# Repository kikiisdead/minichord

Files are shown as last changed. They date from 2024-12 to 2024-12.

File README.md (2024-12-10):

# MINICHORD
 a mini omnichord made using Teensy 4.1 and the Teensy Audio Library for Digital Electronics at NYU Steinhardt Music Tech

# HARDWARE
 - Teensy 4.1 (could probably use a cheaper version but I have not tested it)
 - Teensy Audio Head
 - Adafruit CAP1188 
 - 7 MX compatible key switches (or equivalent, I used some Adafruit ones)
 - Adafruit SSD1306 (you may need to change the device ID)
 - Alps EC12E Vertical Rotary Encoder

[Mouser Project Page](https://www.mouser.com/ProjectManager/ProjectDetail.aspx?AccessID=75f0d25f79)

Does not include header pins, standoffs, or the cost to print the PCB.

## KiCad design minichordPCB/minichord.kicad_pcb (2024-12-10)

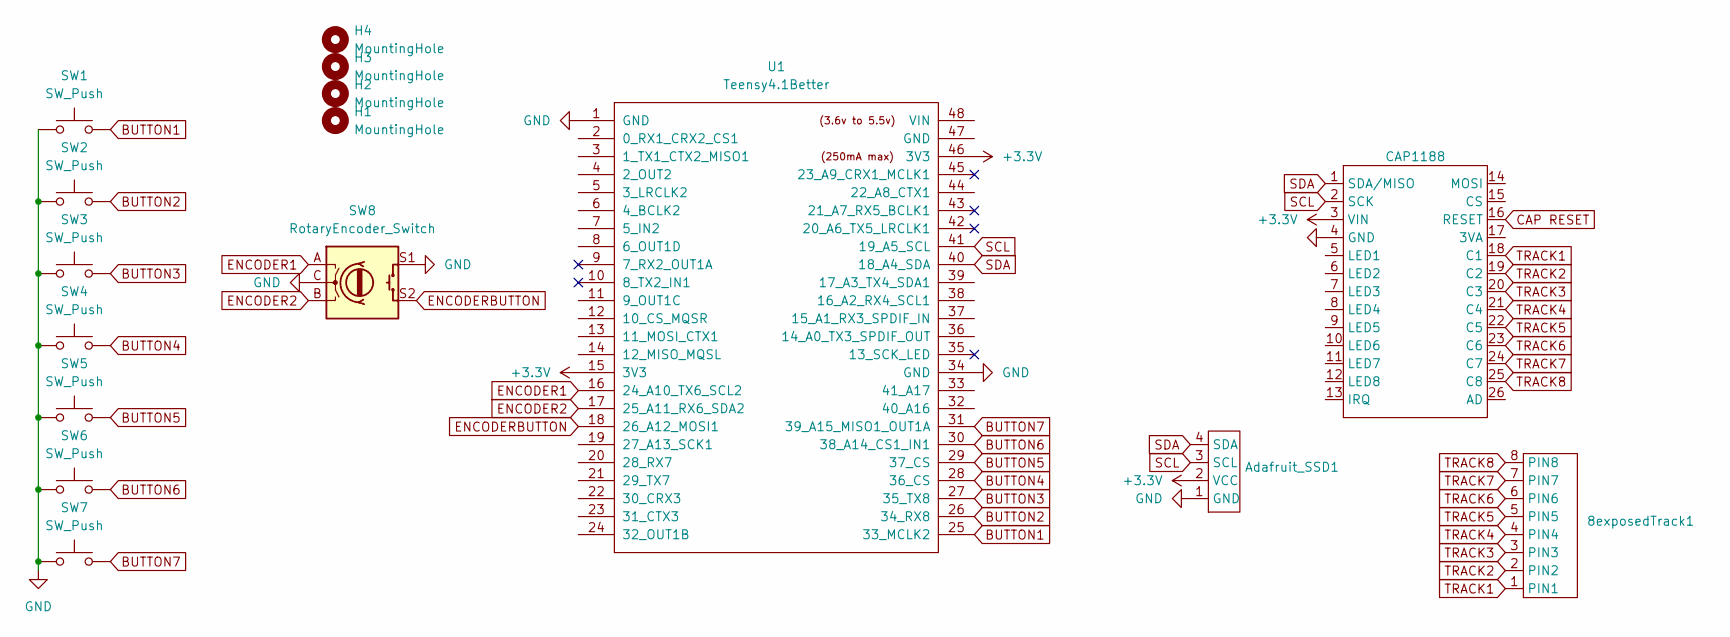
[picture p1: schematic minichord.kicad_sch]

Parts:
8exposedTrack1: 8touchCapacitiveTouch
Adafruit_SSD1: OLED_From_Amazon
H1, H2, H3, H4: MountingHole; MountingHole_2.7mm_M2.5
SW1, SW2, SW3, SW4, SW5, SW6, SW7: SW_Push; SW_Cherry_MX_1.00u_PCB
SW8: RotaryEncoder_Switch; RotaryEncoder_Alps_EC12E-Switch_Vertical_H20mm
U1: Teensy4.1Better; Teensy41Better
adafruit1: CAP1188; CAP1188 BREAKOUT

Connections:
+3.3V: Adafruit_SSD1.2 (VCC), U1.15 (3V3), U1.46 (3V3), adafruit1.3 (VIN)
BUTTON1: SW1.2, U1.25 (33_MCLK2)
BUTTON2: SW2.2, U1.26 (34_RX8)
BUTTON3: SW3.2, U1.27 (35_TX8)
BUTTON4: SW4.2, U1.28 (36_CS)
BUTTON5: SW5.2, U1.29 (37_CS)
BUTTON6: SW6.2, U1.30 (38_A14_CS1_IN1)
BUTTON7: SW7.2, U1.31 (39_A15_MISO1_OUT1A)
CAP RESET: adafruit1.16 (RESET)
ENCODER1: SW8.A, U1.16 (24_A10_TX6_SCL2)
ENCODER2: SW8.B, U1.17 (25_A11_RX6_SDA2)
ENCODERBUTTON: SW8.S2, U1.18 (26_A12_MOSI1)
GND: Adafruit_SSD1.1 (GND), SW1.1, SW2.1, SW3.1, SW4.1, SW5.1, SW6.1, SW7.1, SW8.C, SW8.S1, U1.1 (GND), U1.34 (GND), adafruit1.4 (GND)
SCL: Adafruit_SSD1.3 (SCL), U1.41 (19_A5_SCL), adafruit1.2 (SCK)
SDA: Adafruit_SSD1.4 (SDA), U1.40 (18_A4_SDA), adafruit1.1 (SDA/MISO)
TRACK1: 8exposedTrack1.1 (PIN1), adafruit1.18 (C1)
TRACK2: 8exposedTrack1.2 (PIN2), adafruit1.19 (C2)
TRACK3: 8exposedTrack1.3 (PIN3), adafruit1.20 (C3)
TRACK4: 8exposedTrack1.4 (PIN4), adafruit1.21 (C4)
TRACK5: 8exposedTrack1.5 (PIN5), adafruit1.22 (C5)
TRACK6: 8exposedTrack1.6 (PIN6), adafruit1.23 (C6)
TRACK7: 8exposedTrack1.7 (PIN7), adafruit1.24 (C7)
TRACK8: 8exposedTrack1.8 (PIN8), adafruit1.25 (C8)

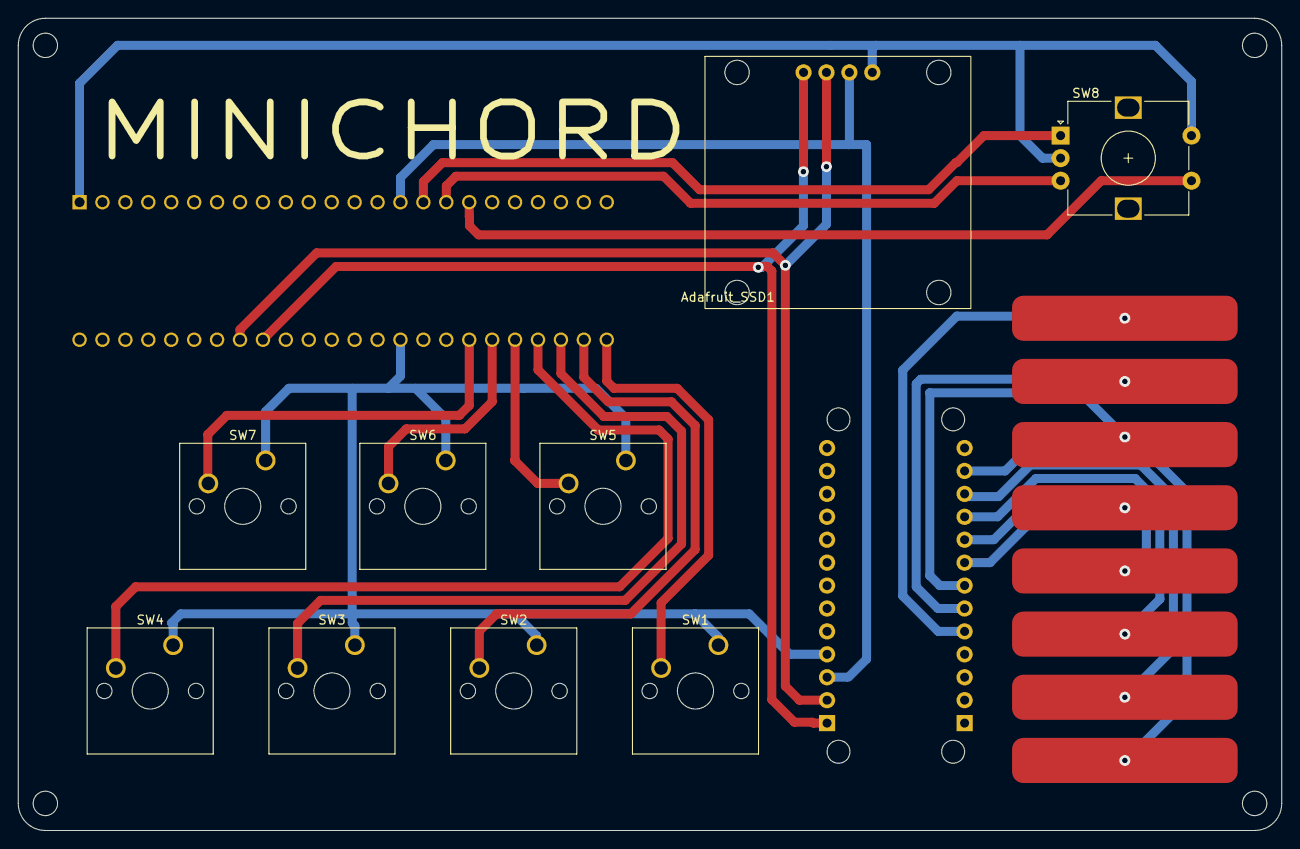
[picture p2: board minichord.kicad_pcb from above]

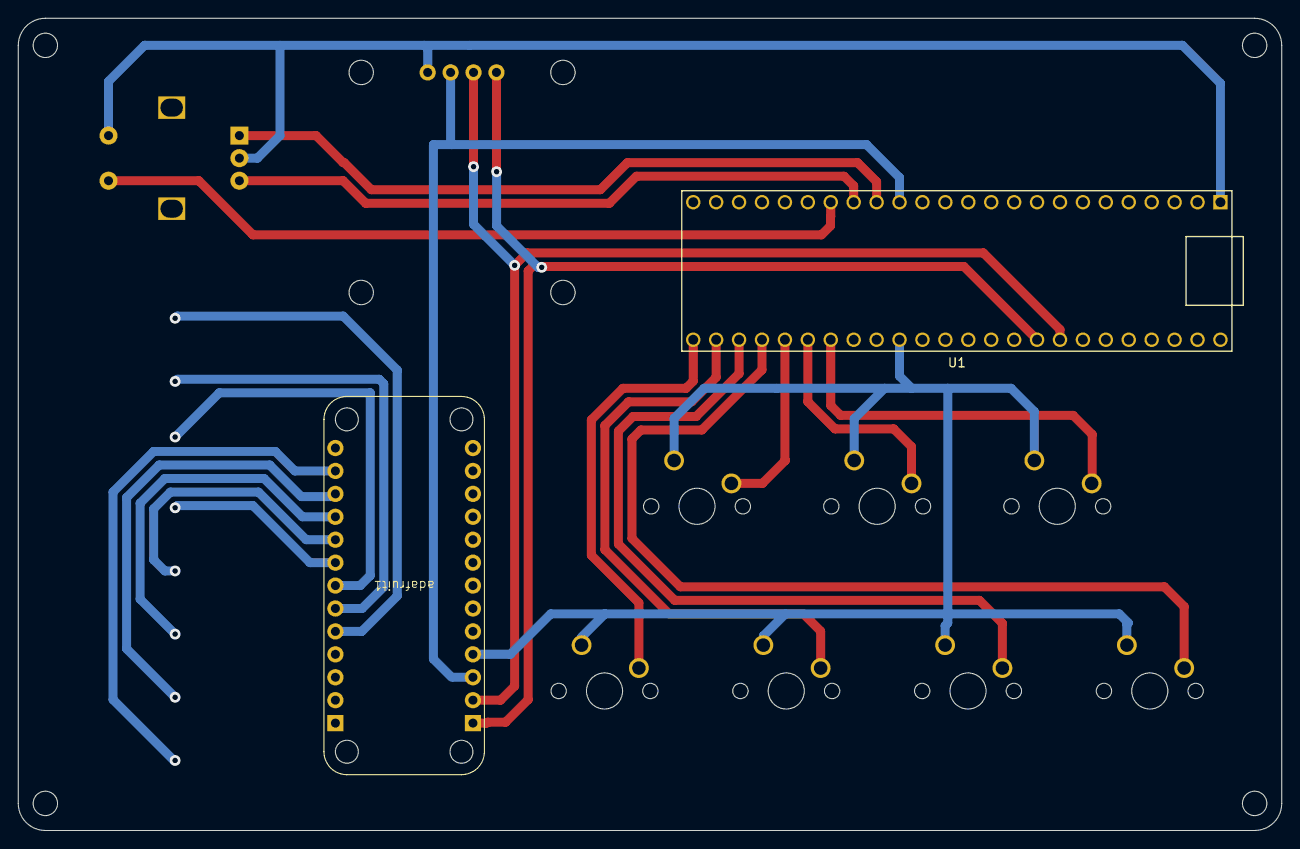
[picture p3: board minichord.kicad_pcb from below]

Board: 2 copper layers, 140.0 x 90.0 mm, 16 parts (2 on the bottom side), 22 nets.

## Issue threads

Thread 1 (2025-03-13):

Build process via PlatformIO fails. Libraries used for original project are not specified.

sinitsinmike, 2025-03-13:
There's an issue during a build process via PlatformIO.

Exect libraries used for original projetc not specified.

Processing teensy41 (platform: teensy; board: teensy41; framework: arduino)
----------------------------------------------------------------------------------------------------------------------------
Verbose mode can be enabled via `-v, --verbose` option
CONFIGURATION: https://docs.platformio.org/page/boards/teensy/teensy41.html
PLATFORM: Teensy (5.0.0) > Teensy 4.1
HARDWARE: IMXRT1062 600MHz, 512KB RAM, 7.75MB Flash
DEBUG: Current (jlink) External (jlink)
PACKAGES:
 - framework-arduinoteensy @ 1.159.0 (1.59)
 - tool-teensy @ 1.159.0 (1.59)
 - toolchain-gccarmnoneeabi-teensy @ 1.110301.0 (11.3.1)
Converting minichord.ino
LDF: Library Dependency Finder -> https://bit.ly/configure-pio-ldf
LDF Modes: Finder ~ chain, Compatibility ~ soft
Found 112 compatible libraries
Scanning dependencies...
Dependency Graph
|-- Adafruit SSD1306 @ 2.5.13
|-- Adafruit CAP1188 Library @ 1.1.3
|-- SD @ 1.3.0
|-- Audio @ 1.3
|-- EEPROM @ 2.0
|-- SerialFlash
|-- SPI @ 1.0
|-- Wire @ 1.0
|-- Adafruit GFX Library @ 1.12.0
|-- Encoder @ 1.4.4
Building in release mode

Compiling .pio\build\teensy41\libcb2\Audio\analyze_tonedetect.cpp.o

After the line above all text in yellow. indicating some issue:

.pio\libdeps\teensy41\SD\src\File.cpp: In constructor 'SDLib::File::File(SdFile, const char*)':
.pio\libdeps\teensy41\SD\src\File.cpp:25:11: warning: 'void* memcpy(void*, const void*, size_t)' writing to an object of type 'class SdFile' with no trivial copy-assignment; use copy-assignment or copy-initialization instead [-Wclass-memaccess]
   25 |     memcpy(_file, &f, sizeof(SdFile));
      |     ~~~~~~^~~~~~~~~~~~~~~~~~~~~~~~~~~
In file included from .pio\libdeps\teensy41\SD\src/SD.h:20,
                 from .pio\libdeps\teensy41\SD\src\File.cpp:15:
.pio\libdeps\teensy41\SD\src/utility/SdFat.h:151:7: note: 'class SdFile' declared here
  151 | class SdFile : public Print {
      |       ^~~~~~
Archiving .pio\build\teensy41\lib98b\libAdafruit SSD1306.a
.pio\libdeps\teensy41\SD\src\utility\SdFile.cpp: In member function 'uint8_t SdFile::open(SdFile*, const char*, uint8_t)':
Archiving .pio\build\teensy41\libecb\libAdafruit CAP1188 Library.a
.pio\libdeps\teensy41\SD\src\utility\SdFile.cpp:532:15: warning: taking address of packed member of 'directoryEntry' may result in an unaligned pointer value [-Waddress-of-packed-member]
  532 |     dateTime_(&p->creationDate, &p->creationTime);
      |               ^~~~~~~~~~~~~~~~
.pio\libdeps\teensy41\SD\src\utility\SdFile.cpp:532:15: warning: taking address of packed member of 'directoryEntry' may result in an unaligned pointer value [-Waddress-of-packed-member]
.pio\libdeps\teensy41\SD\src\utility\SdFile.cpp:532:33: warning: taking address of packed member of 'directoryEntry' may result in an unaligned pointer value [-Waddress-of-packed-member]
  532 |     dateTime_(&p->creationDate, &p->creationTime);
      |                                 ^~~~~~~~~~~~~~~~
.pio\libdeps\teensy41\SD\src\utility\SdFile.cpp:532:33: warning: taking address of packed member of 'directoryEntry' may result in an unaligned pointer value [-Waddress-of-packed-member]
.pio\libdeps\teensy41\SD\src\utility\SdFile.cpp: In member function 'uint8_t SdFile::sync(uint8_t)':
.pio\libdeps\teensy41\SD\src\utility\SdFile.cpp:1155:17: warning: taking address of packed member of 'directoryEntry' may result in an unaligned pointer value [-Waddress-of-packed-member]
 1155 |       dateTime_(&d->lastWriteDate, &d->lastWriteTime);
      |                 ^~~~~~~~~~~~~~~~~
.pio\libdeps\teensy41\SD\src\utility\SdFile.cpp:1155:17: warning: taking address of packed member of 'directoryEntry' may result in an unaligned pointer value [-Waddress-of-packed-member]
.pio\libdeps\teensy41\SD\src\utility\SdFile.cpp:1155:36: warning: taking address of packed member of 'directoryEntry' may result in an unaligned pointer value [-Waddress-of-packed-member]
 1155 |       dateTime_(&d->lastWriteDate, &d->lastWriteTime);
      |                                    ^~~~~~~~~~~~~~~~~
.pio\libdeps\teensy41\SD\src\utility\SdFile.cpp:1155:36: warning: taking address of packed member of 'directoryEntry' may result in an unaligned pointer value [-Waddress-of-packed-member]

tried the following SD lib: arduino-libraries/SD@^1.3.0
braydenanderson2014/BasicIOStream@^1.0.1

kikiisdead, 2025-03-13:
The way I have the PlatformIO project set up is that it's accessing the externals from the Arduino library. This is because I ported the project into VSCode from Arduino. You will have to install Arduino, install the dependencies, and it should work?

sinitsinmike, 2025-03-13:
Which particular SD library was used in this project? Also which version?

Closed 2025-03-13.

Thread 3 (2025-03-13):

Audio shield optional or required?

sinitsinmike, 2025-03-13:
If this device is assambled without the audio shield, then flashed.
Would it be able to work via USB MIDI?
Or the device would fail to boot and get in to infinite loop, waiting for the audio shield?
Would another dac work instead of the shield?
Perhaps pcm5102?

Closed 2025-03-13.

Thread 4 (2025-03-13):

Hex file

sinitsinmike, 2025-03-13:
Success, Tried to build it on Mac, instead of Windows and build process completed with no issues.
The display is lit up but blank. Just the snow, like on the old crt tv :)

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

kikiisdead, 2025-03-13:
There's an error on the PCB, make sure that the SDA and SCL buses are in the right place.

kikiisdead, 2025-03-21:
Sorry scratch that, the GND and VCC pins are swapped. I would just get some wire and attach it.

sinitsinmike, 2025-03-21:
If I plug the display up side down then pinout matches. I'll leave it like this for now, this is good enough for testing perposes ;)

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

Closed 2025-03-21.

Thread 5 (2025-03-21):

After successful build and upload, device restarts every 5-10 seconds. Blank screen. No sound.

sinitsinmike, 2025-03-21:
After compiling and uploading the code to teensy, I get the message in the terminal: CAP1188 found!, SSD1306 allocation success! And that's it, no further messages. Display is blank, and device restarts every 5-10 seconds. Your inpit would be greatly appreciated! Thank you!

sinitsinmike, 2025-03-21:
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

kikiisdead, 2025-03-21:
I just want to make sure that the audio head is installed correctly. Do you mind sending a picture of the bottom side of the board?

sinitsinmike, 2025-03-21:
I am using an alternative board. It is PCM5102. It is connected correctly. I've executed a simple code with a sine wave to make sure there's oudio out. I've ordered the audio shield you've used. It is in the mail. Will get it in a few weeks.

Yahoo Почта: Поиск, организация, успех

  пт, 21 мар. 2025 в 19:20 ***@***.***> написал(-а):
I just want to make sure that the audio head is installed correctly. Do you mind sending a picture of the bottom side of the board?

—
Reply to this email directly, view it on GitHub, or unsubscribe.
You are receiving this because you authored the thread.Message ID: ***@***.***>
kikiisdead left a comment (kikiisdead/minichord#5)
I just want to make sure that the audio head is installed correctly. Do you mind sending a picture of the bottom side of the board?

—
Reply to this email directly, view it on GitHub, or unsubscribe.
You are receiving this because you authored the thread.Message ID: ***@***.***>

sinitsinmike, 2025-03-21:
Also tried various displays with 0x3D and 0x3C addresses, adjusting the address in the code. Previously that didn't work, with your last changes both displays display text. But, rotating the encoder doesn't change any parameters. the text remais unchanged.

kikiisdead, 2025-03-21:
From what I can tell, the issue lies either in the EEPROM read or in the audio connection side of the code. I want to make sure that it is not a hardware issue that's why I'm asking for photos.

sinitsinmike, 2025-03-21:
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
Here are a few photos of the wiring.

sinitsinmike, 2025-03-21:
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

Closed 2025-03-21.

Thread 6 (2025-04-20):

Audio shield board

sinitsinmike, 2025-04-20:
Does your audio shield has an optional W25Q128JV or W25Q128FV chip soldered underneath? Or perhaps a 23LC1024 chip?

My Teensy doesn't have this chip, and that might be the reason why my Minichord doesn't fully boot up.

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

The mem chip on the photo. The docs and wiki says it is optional.
Does your shield has this solderred on?

Thank you!

kikiisdead, 2025-04-21:
I don't have a mem chip on mine. The oscillators don't use any memory and I'm not playing any samples. The only place that uses memory is saving chords between startup and shutdown which happens on the EEPROM. Can you describe what's happening?

sinitsinmike, 2025-04-21:
Previously I've raised the issue that minichord would not boot. Previously I've used different DAC.
You've replued that I have to use Teensy ausio shield.
I got that specific shield, but still no luck booting. I get the text on the screen, but no reaction to encoder nor to 3ncoder button presses.
The touch works, no sound, but the leds light up on touch board, so soldering is fine.
I have also tried alternative simple code to check the teensy audio board, and it produces sound, but not with minichord code.
Not sure what to try next.

Would realky appreciate any suggestions.
Yhank you!
Michael

kikiisdead, 2025-04-21:
Are you getting the message "I'm working" to the Serial Monitor?

sinitsinmike, 2025-04-21:
Ah, no. Not getting "I'm working" to the Serial Monitor.
Auto-restart is still happening every 10 seconds.
Rotating the encoder and or pressing buttons nor strumming doesn't make any difference. No sound. Rotating the encoder doesn't change anything on the screen.

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

Earlier, in another issue/git ticket you wrote:
"From what I can tell, the issue lies either in the EEPROM read or in the audio connection side of the code. From your photos, it looks like the program is stalling in the setup phase after the display and after the capacitive touch sensor. It never reaches the end of the setup phase because "I'm working" is not being printed to the terminal. This means that either the EEPROM.read is failing or the audio shield is not starting correctly.

The reason why the text on screen isn't changing is because we never reach the loop part of the program where that logic is handled. Everything is stalling in the set-up portion."
So something is off.
I've soldered everything correctly.
Ran some test code to check teensy audio shield, and it produces sound. So it is soldered correctly.

sinitsinmike, 2025-04-21:
May be audio libraries got updated. May be I should try to build using older arduino libraries.

kikiisdead, 2025-04-22:
I don't think it's a dependency issue as it seems to be building okay on my end, but try it and let me know if it works.

The program was seems to be written to the Teensy OK as it entered Serial mode and started printing things to the serial monitor. My hunch is that it might not have enough power or there is some sort of other runtime error. Do you know if the USB port you're using is powered?

kikiisdead, 2025-04-22:
I pushed an update that has a more verbose setup function so that there is more specificity where it is crashing.

sinitsinmike, 2025-04-22:
Unfortunately the serial output hasn't changed.

Reconnecting to /dev/cu.usbmodem162834701        Connected!
CAP1188 found!
SSD1306 allocation success!
Disconnected (read failed: [Errno 6] Device not configured)

sinitsinmike, 2025-04-22:
My Teensy audio shield is Rev D2.

sinitsinmike, 2025-04-22:
In January 2023, Rev D2 was created due to shortages on the 32 pin version of SGTL5000 and the [original SD socket](https://forum.pjrc.com/threads/71669). Rev D2 is functionally the same as Rev D, except the the I2C address selection pads. The I2C address is not configurable on the 20 pin SGTL5000 chip.

Could this be an issue?

sinitsinmike, 2025-04-22:
If I comment out:

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
The code goes a bit further.
So looks like initRoot(EEPROM.read(i)) is causing this.

kikiisdead, 2025-04-22:
`
#include <EEPROM.h>

int write = 10;

int read = 0;

void setup() {
  // put your setup code here, to run once:
  Serial.begin(9600);
  EEPROM.write(0, write);
  Serial.println(F("writing to EEPROM"));
  read = EEPROM.read(0);
  Serial.println(F("Reading from EEPROM"));
  Serial.println(read);
  while (true) {
  }
}

void loop() {
  // put your main code here, to run repeatedly:

}
`

could you test this code to see if the EEPROM is messing things up?

sinitsinmike, 2025-04-22:
16:56:13.381 -> writing to EEPROM
16:56:13.381 -> Reading from EEPROM
16:56:13.381 -> 10

sinitsinmike, 2025-04-22:
If I run:

/* EEPROM Read
 *
 * Reads the value of each byte of the EEPROM and prints it
 * to the computer.
 */

#include <EEPROM.h>

// start reading from the first byte (address 0) of the EEPROM
int address = 0;
byte value;

void setup()
{
  Serial.begin(9600);
}

void loop()
{
  // read a byte from the current address of the EEPROM
  value = EEPROM.read(address);

  Serial.print(address);
  Serial.print("\t");
  Serial.print(value, DEC);
  Serial.println();

  // advance to the next address of the EEPROM
  address = address + 1;

  // there are only 512 bytes of EEPROM, from 0 to 511, so if we're
  // on address 512, wrap around to address 0
  if (address == 512)
    address = 0;
  // Teensy 1.0 has 512 bytes
  // Teensy 2.0 has 1024 bytes
  // Teensy++ 1.0 has 2048 bytes
  // Teensy++ 2.0 has 4096 bytes

  delay(500);
}

I get:

16:56:13.381 -> writing to EEPROM
16:56:13.381 -> Reading from EEPROM
16:56:13.381 -> 10
16:57:15.049 -> 0	10
16:57:15.494 -> 1	0
16:57:16.021 -> 2	255
16:57:16.516 -> 3	0
16:57:17.010 -> 4	0
16:57:17.506 -> 5	0
16:57:18.000 -> 6	255
16:57:18.495 -> 7	255
16:57:19.020 -> 8	255
16:57:19.515 -> 9	255
16:57:20.008 -> 10	255
16:57:20.502 -> 11	0
16:57:20.995 -> 12	255
16:57:21.523 -> 13	0
16:57:22.017 -> 14	0
16:57:22.512 -> 15	0
16:57:23.008 -> 16	255
16:57:23.503 -> 17	255
16:57:23.998 -> 18	255
16:57:24.526 -> 19	255
16:57:25.017 -> 20	255

sinitsinmike, 2025-04-22:
Correction.
If I try modifying your code in minichord.ino like this:

    chords[i]->initRoot(EEPROM.read(i));
    Serial.println(F("EEPROM!"));
    chords[i]->setChordType((chordTypes)(EEPROM.read(i + 10)));
    Serial.println(F("Set Chord type!"));

I get the first serial print: EEPROM!
But I don't get the second one: Set Chord type!

So Set Chord type! never gets printed.

kikiisdead, 2025-04-22:
it might be something to do with the type casting from an enum. I'll see what I can do once my parts get in tomorrow.

sinitsinmike, 2025-04-23:
Swapped places 24 and 25, encoder works fine now.
Thanks again!

kikiisdead, 2025-04-23:
Of course I'm glad we figured it out!

Closed 2025-04-23.

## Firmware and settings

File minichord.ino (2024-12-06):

#include "chord.h"
#include "betterEncoder.h"
#include "voice.h"
#include "mixers.h"
#include "velocity.h"
#include "volume.h"
#include "chordType.h"
#include "chordRoot.h"
#include "animation.h"
#include <Audio.h>
#include <Wire.h>
#include <SPI.h>
#include <SD.h>
#include <SerialFlash.h>
#include <Adafruit_GFX.h>
#include <Adafruit_SSD1306.h>
#include <Adafruit_CAP1188.h>
#include <string.h>
#include <EEPROM.h>

// MEMORY ALLOCATION
// Addresses 0-6 are for the root note
// Addresses 10-16 are for the chord type
// don't want to write too many times so only write when changing off of the corresponding editMode

#define CHORDPIN1 33
#define CHORDPIN2 34
#define CHORDPIN3 35
#define CHORDPIN4 36
#define CHORDPIN5 37
#define CHORDPIN6 38
#define CHORDPIN7 39
#define EDITPIN 26

#define ROOTEDIT 0
#define CHORDEDIT 1
#define VOLEDIT 2
#define VELEDIT 3
#define ANIM 4

#define CAP1188_RESET -1

#define SCREEN_WIDTH 128     // OLED display width, in pixels
#define SCREEN_HEIGHT 64     // OLED display height, in pixels
#define OLED_RESET -1        // Reset pin # (or -1 if sharing Arduino reset pin)
#define SCREEN_ADDRESS 0x3C  ///< See datasheet for Address; 0x3D for 128x64, 0x3C for 128x32

Adafruit_SSD1306 display(SCREEN_WIDTH, SCREEN_HEIGHT, &Wire, OLED_RESET);

Adafruit_CAP1188 cap = Adafruit_CAP1188();

Voice sustainVoice1(WAVEFORM_TRIANGLE, 0.5);
Voice sustainVoice2(WAVEFORM_TRIANGLE, 0.5);
Voice sustainVoice3(WAVEFORM_TRIANGLE, 0.5);
Voice strumVoice1(WAVEFORM_TRIANGLE, 0.5);
Voice strumVoice2(WAVEFORM_TRIANGLE, 0.5);
Voice strumVoice3(WAVEFORM_TRIANGLE, 0.5);
Voice strumVoice4(WAVEFORM_TRIANGLE, 0.5);
Voice strumVoice5(WAVEFORM_TRIANGLE, 0.5);
Voice strumVoice6(WAVEFORM_TRIANGLE, 0.5);
Voice strumVoice7(WAVEFORM_TRIANGLE, 0.5);
Voice strumVoice8(WAVEFORM_TRIANGLE, 0.5);

Voice* voices[11] = { &sustainVoice1, &sustainVoice2, &sustainVoice3, &strumVoice1, &strumVoice2, &strumVoice3, &strumVoice4, &strumVoice5, &strumVoice6, &strumVoice7, &strumVoice8 };

AudioMixer11 mixer;
AudioOutputI2S i2sOut;
AudioControlSGTL5000 audioShield;
AudioConnection* patchCords[11];
AudioConnection patchCord1(mixer, 0, i2sOut, 0);
AudioConnection patchCord2(mixer, 0, i2sOut, 1);

Chord chord1(CHORDPIN1);
Chord chord2(CHORDPIN2);
Chord chord3(CHORDPIN3);
Chord chord4(CHORDPIN4);
Chord chord5(CHORDPIN5);
Chord chord6(CHORDPIN6);
Chord chord7(CHORDPIN7);

Voice* sustainVoices[3] = { &sustainVoice1, &sustainVoice2, &sustainVoice3 };
Voice* strumVoices[8] = { &strumVoice1, &strumVoice2, &strumVoice3, &strumVoice4, &strumVoice5, &strumVoice6, &strumVoice7, &strumVoice8 };

Chord* chords[7] = { &chord1, &chord2, &chord3, &chord4, &chord5, &chord6, &chord7 };
Button editButton(EDITPIN);

int editSelector = 0;

Velocity velocity(90);
Volume volume(0.5);
ChordType chordType(chords[editSelector]);
ChordRoot chordRoot(chords[editSelector]);
Animation animation;
EncoderEditable* editMode = &chordRoot; //using pointer so as not to create new object, just point to already existing object

BetterEncoder enc(25, 24, 4);

elapsedMillis holdTime;
elapsedMillis animationTime;

void setup() {
  Serial.begin(9600);
  enc.incrementHandler(encoderIncrement);
  enc.decrementHandler(encoderDecrement);

  //capacitive touch sensor
  if (!cap.begin()) {
    Serial.println("CAP1188 not found");
    while (1)
      ;
  }
  Serial.println("CAP1188 found!");

  //chord objects
  for (int i = 0; i < 7; i++) {
    chords[i]->noteOnHandler(noteOn);
    chords[i]->noteOffHandler(noteOff);
    chords[i]->capCheckHandler(adaCapCheck);
    chords[i]->initRoot(EEPROM.read(i));
    chords[i]->setChordType((chordTypes)(EEPROM.read(i + 10)));
  }

  //display
  if (!display.begin(SSD1306_SWITCHCAPVCC, SCREEN_ADDRESS)) {
    Serial.println(F("SSD1306 allocation failed"));
    while (1)
      ;  // Don't proceed, loop forever
  }
  Serial.println("SSD1306 allocation success!");
  display.clearDisplay();
  displayUI();
  display.display();

  //audio things
  for (int i = 0; i < 11; i++) {
    patchCords[i] = new AudioConnection(voices[i]->envelope, 0, mixer, i);
    mixer.gain(i, 0.5);
  }

  AudioMemory(12);
  audioShield.enable();
  audioShield.volume(volume.getVolume());

  for (int i = 0; i < 3; i++) {
    sustainVoices[i]->setEnvelope(10, 200, 0.6, 80);
  }
  for (int i = 0; i < 8; i++) {
    strumVoices[i]->setEnvelope(10, 250, 0.3, 500);
  }

  //everything works if it hits this point
  Serial.println("I'm working");
}

void loop() {
  enc.process();
  checkEdit();
  checkChordButtons();
  for (int i = 0; i < 7; i++) {
    chords[i]->update();
  }
  if (editMode->getNum() == ANIM) {
    animateStrings();
  }
}

void noteOn(int voice, int noteValue, bool selector) { //going into chord object
  usbMIDI.sendNoteOn(noteValue, velocity.getVelocity(), 1);
  if (selector == SUSTAIN) sustainVoices[voice]->noteOn(noteValue);
  else strumVoices[voice]->noteOn(noteValue);
}

void noteOff(int voice, int noteValue, bool selector) { //going into chord object
  usbMIDI.sendNoteOff(noteValue, 0, 1);
  if (selector == SUSTAIN) sustainVoices[voice]->noteOff(noteValue);
  else strumVoices[voice]->noteOff(noteValue);
}

void adaCapCheck(int noteTouch[8]) { // going into chord object
  uint8_t touched = cap.touched();
  for (uint8_t i = 0; i < 8; i++) {
    if (touched & (1 << i)) noteTouch[i] = HIGH;  //simply returning the position that it is touched/which cap is being touched. returns whichever is firt so only one touch position;
    else noteTouch[i] = LOW;
  }
}

void encoderIncrement() { // going into BetterEncoder Object
  chordRoot.setChord(chords[editSelector]);
  chordType.setChord(chords[editSelector]);
  editMode->increment(); // using abstraction through a superclass to call this member function
  audioShield.volume(volume.getVolume());
  if (editMode->getNum() != ANIM) {
    displayUI();
  }
}

void encoderDecrement() { // going into BetterEncoder Object
  chordRoot.setChord(chords[editSelector]);
  chordType.setChord(chords[editSelector]);
  editMode->decrement(); // using abstraction through a superclass to call this member function
  audioShield.volume(volume.getVolume());
  if (editMode->getNum() != ANIM) {
    displayUI();
  }
}

void checkChordButtons() {
  for (int i = 0; i < 7; i ++) {
    if (chords[i]->getButton()->buttonCheck() == 1) {
      editSelector = i;
      if (chords[editSelector]->getRoot() != EEPROM.read(editSelector)) {
        EEPROM.write(editSelector, chords[editSelector]->getRoot());
        Serial.println("Writing root note");
      }
      if ((int)chords[editSelector]->getChordType() != EEPROM.read(editSelector + 10)) {
        EEPROM.write(editSelector + 10, (int)chords[editSelector]->getChordType());
        Serial.println("Writing chord type");
      }
      if (editMode->getNum() != ANIM) {
        displayUI();
      }
    }
  }
}

void checkEdit() {
  editButton.update();
  if (editButton.buttonCheck() == 1) {
    int edit = editMode->getNum();
    edit = (edit < 3) ? edit + 1 : 0;
    if (edit == ROOTEDIT)       editMode = &chordRoot;
    else if (edit == CHORDEDIT) editMode = &chordType;
    else if (edit == VOLEDIT)   editMode = &volume;
    else if (edit == VELEDIT)   editMode = &velocity;
    holdTime = 0;
    displayUI();
  }
  if (editButton.buttonCheck() == 2 && holdTime > 500) {
    editMode = &animation;
  }
}

//UI THINGS
void displayUI() {
  display.clearDisplay();
  display.setTextColor(WHITE);
  displayLabel("Chord Root:", 0);
  displayItem(getChordRoot(), 0);
  displayLabel("Chord Type:", 1);
  displayItem(getChordType(), 1);
  displayLabel("Volume:", 2);
  displayItem(getVolume(), 2);
  displayLabel("Velocity:", 3);
  displayItem(String(velocity.getVelocity()), 3);
  displaySelector(editMode->getNum());
  display.display();
}

void animateStrings() {
  if (animationTime >= 60) {  //slow down to 24 fps so that it is less laggy
    display.clearDisplay();
    for (int i = 0; i < 8; i++) {
      int yLevel = (i * 8) + 4;
      float jitterAmount = strumVoices[i]->readPeak() * 4;
      float prevJitter = 0;
      for (int j = 0; j < display.width(); j += 8) {
        int randomInt = (j < SCREEN_WIDTH - 8) ? random(-4, 5) : 0;
        float jitter = randomInt * jitterAmount;
        display.drawLine(j, yLevel + prevJitter, j + 8, yLevel + jitter, WHITE);
        prevJitter = jitter;
      }
    }
    display.display();
    animationTime = 0;
  }
}

void displayLabel(String labelText, int position) {
  display.setTextSize(1);
  display.setTextColor(WHITE);
  int16_t x1, y1;
  uint16_t w, h;
  display.getTextBounds(labelText, 0, 0, &x1, &y1, &w, &h);
  if (position == 0)      display.setCursor(0, 0);
  else if (position == 1) display.setCursor(0, SCREEN_HEIGHT / 2);
  else if (position == 2) display.setCursor(SCREEN_WIDTH - w, 0);
  else if (position == 3) display.setCursor(SCREEN_WIDTH - w, SCREEN_HEIGHT / 2);
  display.print(labelText);
}

void displayItem(String itemText, int position) {
  display.setTextSize(2);
  display.setTextColor(WHITE);
  int16_t x1, y1;
  uint16_t w, h;
  display.getTextBounds(itemText, 0, 0, &x1, &y1, &w, &h);
  if (position == 0)      display.setCursor(0, 10);
  else if (position == 1) display.setCursor(0, (SCREEN_HEIGHT / 2) + 10);
  else if (position == 2) display.setCursor(SCREEN_WIDTH - w, 10);
  else if (position == 3) display.setCursor(SCREEN_WIDTH - w, (SCREEN_HEIGHT / 2) + 10);
  display.print(itemText);
}

void displaySelector(int position) {
  display.setTextSize(2);
  display.setTextColor(WHITE);
  if (position == 0)      display.setCursor(SCREEN_WIDTH / 2, 10);
  else if (position == 1) display.setCursor(SCREEN_WIDTH / 2, (SCREEN_HEIGHT / 2) + 10);
  else if (position == 2) display.setCursor(SCREEN_WIDTH / 2, 10);
  else if (position == 3) display.setCursor(SCREEN_WIDTH / 2, (SCREEN_HEIGHT / 2) + 10);

  if (position < 2) display.print(F("<"));
  else display.print(F(">"));
}

String getChordRoot() {
  int root = abs(chords[editSelector]->getRoot() % 12);
  if (root == 0)        return "C";
  else if (root == 1)   return "C#/Db";
  else if (root == 2)   return "D";
  else if (root == 3)   return "D#/Eb";
  else if (root == 4)   return "E";
  else if (root == 5)   return "F";
  else if (root == 6)   return "F#/Gb";
  else if (root == 7)   return "G";
  else if (root == 8)   return "G#/Ab";
  else if (root == 9)   return "A";
  else if (root == 10)  return "A#/Bb";
  else if (root == 11)  return "B";
  else                  return "";
}

String getChordType() {
  chordTypes type = chords[editSelector]->getChordType();
  if (type == MAJOR)                    return "Maj";
  else if (type == MINOR)               return "min";
  else if (type == AUGMENTED)           return "aug";
  else if (type == DIMINISHED)          return "dim";
  else if (type == MAJORSEVEN)          return "Maj7";
  else if (type == MINORSEVEN)          return "min7";
  else if (type == DOMINANTSEVEN)       return "dom7";
  else if (type == HALFDIMINISHEDSEVEN) return "m7b5";
  else if (type == FULLDIMINISHEDSEVEN) return "dim7";
  else                                  return "";
}

String getVolume() {
  String volStr = String(volume.getVolume(), 2);
  return volStr;
}

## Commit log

2024-11-18 Added Interface for Encoder Editable Parameters
    Basically utilizing pointers to simplyfy my encoder increment and decrement functions
2024-12-04 KiCad Files for the PCB
    [minichord-B_Cu.gbr, minichord-B_Mask.gbr, minichord-B_Paste.gbr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]
2024-12-04 changed name of folder in directory
    [minichord-B_Cu.gbr, minichord-B_Mask.gbr, minichord-B_Paste.gbr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]
2024-12-05 KiCad Footprints and symbols for CAP1188
2024-12-11 fixing smal display issue
    [minichord.ino]
